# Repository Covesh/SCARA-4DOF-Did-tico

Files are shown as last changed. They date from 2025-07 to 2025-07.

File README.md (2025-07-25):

# Desenvolvimento de um Robô Manipulador SCARA para Fins Didáticos

Este repositório contém os recursos de um projeto focado na conceção, implementação e validação de um robô manipulador SCARA de baixo custo, desenvolvido especificamente para fins didáticos no ensino de robótica. O objetivo é proporcionar uma plataforma prática para o estudo de conceitos fundamentais da mecatrónica e controlo robótico.

  <div align="center">
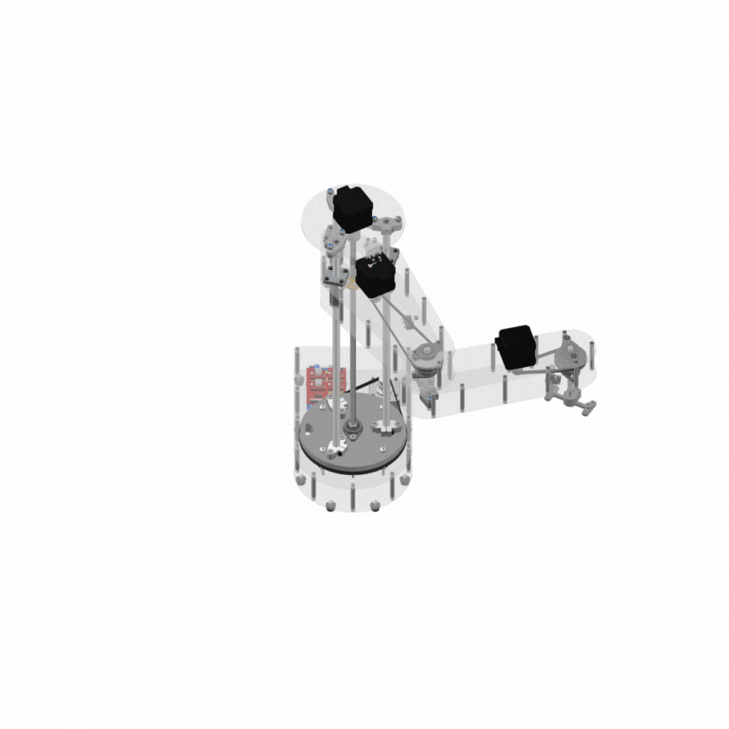
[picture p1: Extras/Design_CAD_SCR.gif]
Design CAD do Robô SCARA
      
      <em>Um GIF que ilustra o design e os movimentos do robô no software CAD.</em>
  </div>

## Descrição do Projeto

O robô é um manipulador do tipo SCARA com 4 graus de liberdade (GDL), onde a sua cinemática inversa foi implementada para uma configuração de 3 GDL (2 rotacionais e 1 prismático), com um 4º GDL rotacional no efetuador final. A sua estrutura é projetada para simplicidade, boa visibilidade dos componentes e fácil acesso, utilizando materiais como acrílico (corte a laser) e PLA (impressão 3D).

<div align="center">
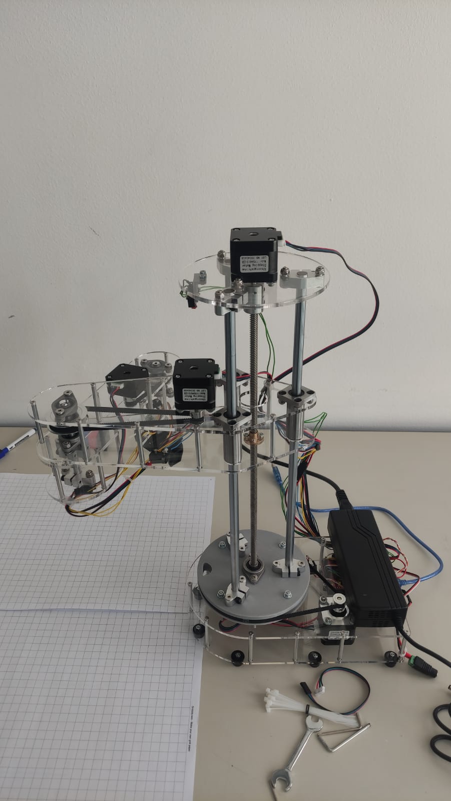
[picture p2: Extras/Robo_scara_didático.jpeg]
Robô SCARA Didático
  
</div>

## Conteúdo do Repositório

* **`💻 /code/arduino`**: Contém o firmware desenvolvido em C/C++ para a placa Arduino Uno, responsável pelo controlo de baixo nível dos motores de passo e do servo motor. Utiliza a biblioteca AccelStepper para perfis de movimento suaves.
* **`🐍 /code/python`**: Contém o software de alto nível (HMI - Interface Gráfica do Utilizador) desenvolvido em Python. Este software realiza cálculos cinemáticos, gere a comunicação serial com o Arduino, e permite a interação do utilizador, incluindo o controlo manual e a gestão de sequências de movimento.
* **`📐 /cad`**: Contém os modelos 3D do manipulador SCARA, desenhados em software CAD (Autodesk Inventor). Inclui ficheiros para corte a laser (.dxf) e impressão 3D (.stl), que podem ser utilizados para replicar a estrutura mecânica.
* **`📄 /docs`**: (A ser adicionado) Documentação detalhada do projeto, incluindo o relatório final, que aborda a fundamentação teórica, o processo de design, a análise cinemática, os testes experimentais e as conclusões.
* **`🎥 /videos`**: Contém vídeos demonstrativos dos testes de funcionamento do robô, incluindo operações de "pick and place" e outros movimentos.

## Principais Funcionalidades e Características ✨

* **Conceção Modular:** Integração de subsistemas mecânicos, eletrónicos e de software.
* **Controlo Abrangente:** Implementação de modelos de cinemática direta e inversa para controlo de movimento preciso.
* **Controlo Eletrónico:** Baseado em Arduino Uno e CNC Shield V3, com drivers A4988 para motores de passo e servo motor para a garra.
* **Interação com Utilizador:** HMI em Python que permite controlo por coordenadas cartesianas/angulares e gestão de sequências.
* **Plataforma Didática:** Recurso de baixo custo e replicável para aprendizagem prática de robótica.

## Demonstrações Visuais ▶️

Aqui pode encontrar exemplos visuais do robô em funcionamento:

* **Vídeos dos Testes:**
    Thumbnail do Vídeo 1 (https://www.youtube.com/watch?v=VIDEO_ID_1)
    _Vídeo 1: Teste de Exatidão e Precisão Posicional._
    Thumbnail do Vídeo 2 (https://www.youtube.com/watch?v=VIDEO_ID_2)
    _Vídeo 2: Demonstração da Tarefa de Pick and Place com Peças de LEGO._

## Como Utilizar 🛠️

Para configurar e operar o robô, siga os passos abaixo:

### Requisitos de Hardware

Certifique-se de que possui os seguintes componentes montados e conectados conforme o diagrama de ligações:

* **Placa Microcontroladora:** Arduino UNO
* **Shield de Expansão:** CNC Shield V3
* **Drivers de Motor de Passo:** 4x A4988
* **Motores de Passo:** 4x NEMA 17 (Modelos HS4023 e 17HS4401S)
* **Servo Motor:** 1x MG996R (para a garra)
* **Sensores de Fim de Curso:** 4x Micro-interruptores de fim de curso
* **Fonte de Alimentação:** 12V (capacidade mínima de 5A, idealmente 9A)
* **Conversor Step-Down:** Para fornecer 5V ao servo motor (se não for alimentado pelo Arduino).
* **Estrutura Mecânica:** Componentes do braço, transmissão (correias e polias), base.

### Requisitos de Software

* **Ambiente de Desenvolvimento Arduino:**
    * Arduino IDE
    * Biblioteca AccelStepper: Pode ser instalada via Gestor de Bibliotecas do Arduino IDE.

* **Ambiente de Desenvolvimento Python:**
    * Python 3.x
    * Bibliotecas Python (podem ser instaladas via `pip`):
        ```bash
        pip install pyserial
        pip install PySide6 # ou PyQt6
        pip install numpy
        pip install pygame
        ```

### Passos de Configuração e Execução

1.  **Montagem do Hardware:** Siga os diagramas de ligação e as instruções de montagem mecânica para construir o robô.
2.  **Upload do Firmware:**
    * Abra o ficheiro `.ino` do firmware localizado em `/code/arduino` na Arduino IDE.
    * Conecte o Arduino ao computador via USB.
    * Selecione a porta e a placa corretas na Arduino IDE.
    * Carregue o firmware para o Arduino.
3.  **Execução do Software HMI:**
    * Navegue até a pasta `/code/python` no seu terminal/linha de comandos.
    * Execute o script principal (geralmente `main.py` ou `hmi.py`):
        ```bash
        python seu_script_principal.py
        ```
4.  **Conexão e Calibração:**
    * A interface gráfica deverá iniciar.
    * Verifique a porta serial correta nas configurações do software Python (se aplicável).
    * Estabeleça a comunicação.
    * Execute a rotina de calibração automática ("Homing") no robô usando a GUI.
5.  **Operação:** Uma vez calibrado, poderá utilizar os controlos da HMI para movimentar o robô, criar e executar sequências, e testar as suas funcionalidades.

## Contribuição 🤝

Este projeto é um esforço académico que visa contribuir para o ensino da robótica.

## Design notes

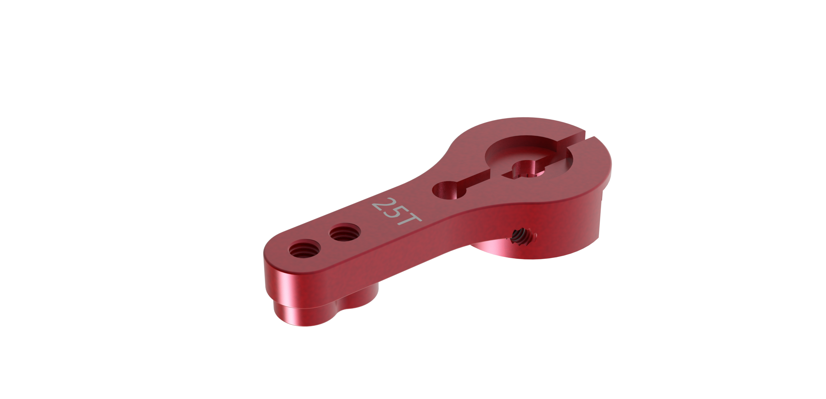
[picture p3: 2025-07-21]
Estrutura Mecânica/SERVO ARM HORN 25T ALUMINIUM/SERVO ARM HORN 25T ALUMINIUM.png

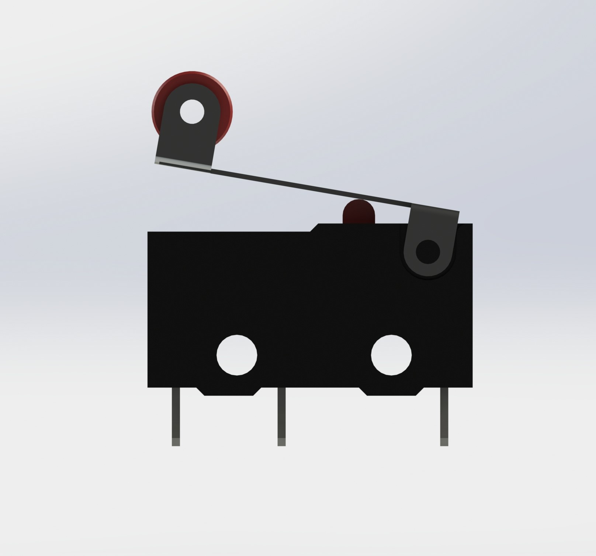
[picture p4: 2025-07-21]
Estrutura Mecânica/Limit switch/render_2.JPG

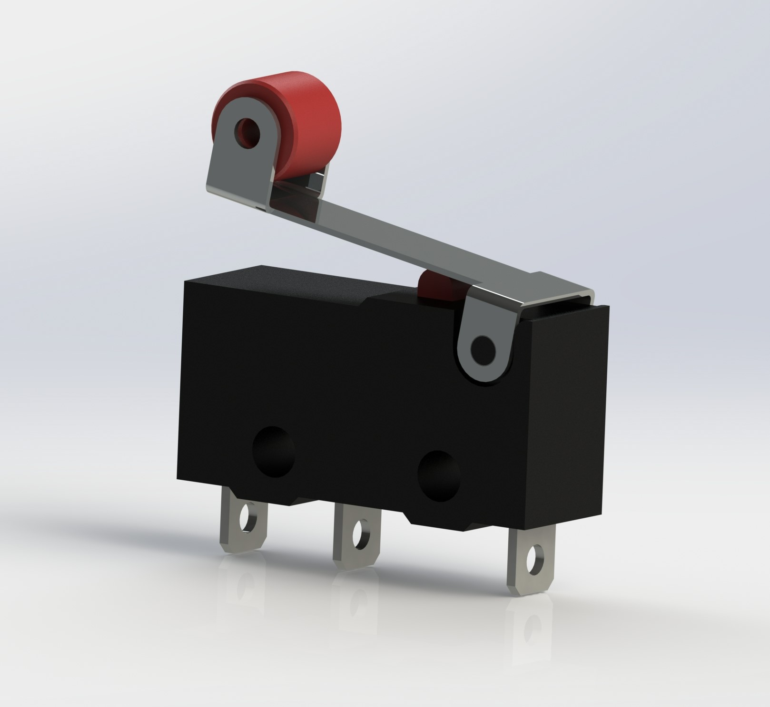
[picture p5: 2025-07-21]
Estrutura Mecânica/Limit switch/render_3.JPG

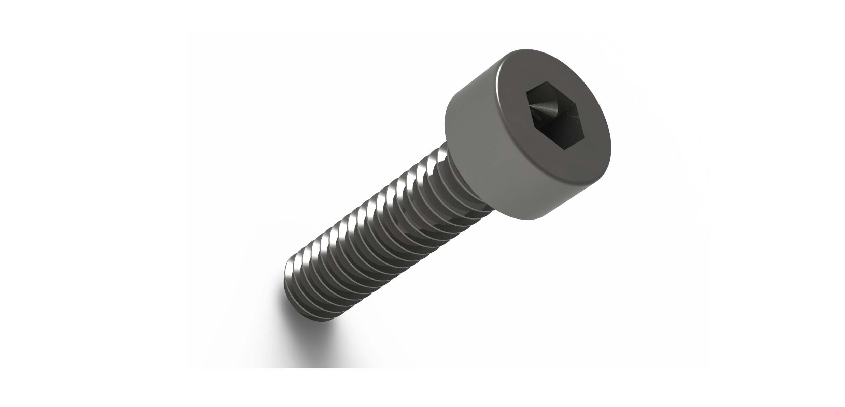
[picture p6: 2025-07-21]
Estrutura Mecânica/SERVO ARM HORN 25T ALUMINIUM/M2 x 8 CAP HEAD HEX SCREW.png

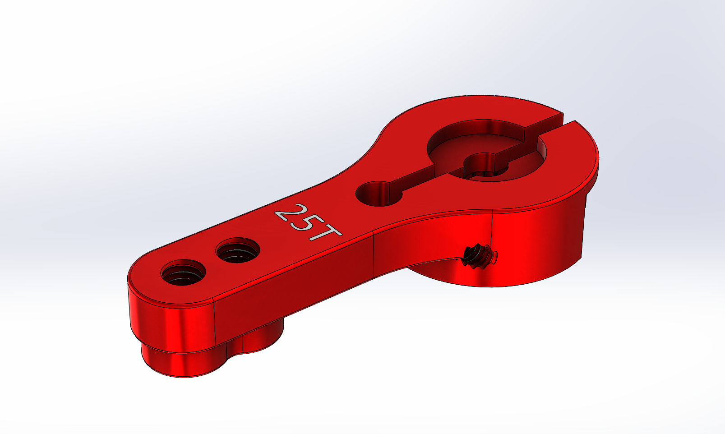
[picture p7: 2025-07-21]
Estrutura Mecânica/SERVO ARM HORN 25T ALUMINIUM/SERVO ARM HORN 25T ALUMINIUM SCREEN GRAB.png

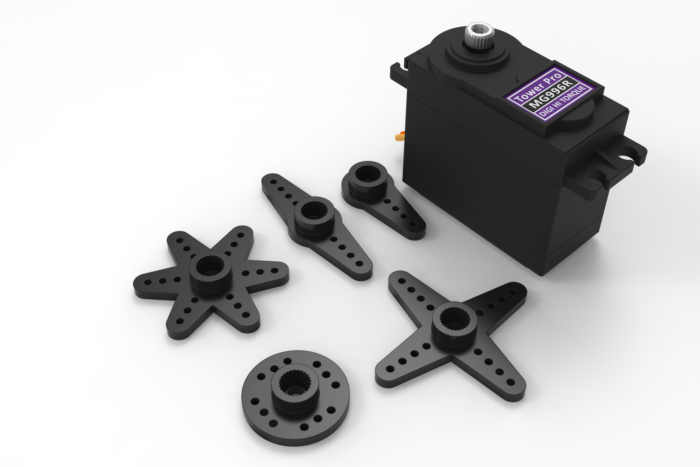
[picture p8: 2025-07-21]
Estrutura Mecânica/MG996R Servo Motor/MG996R Servo Motor.65.png

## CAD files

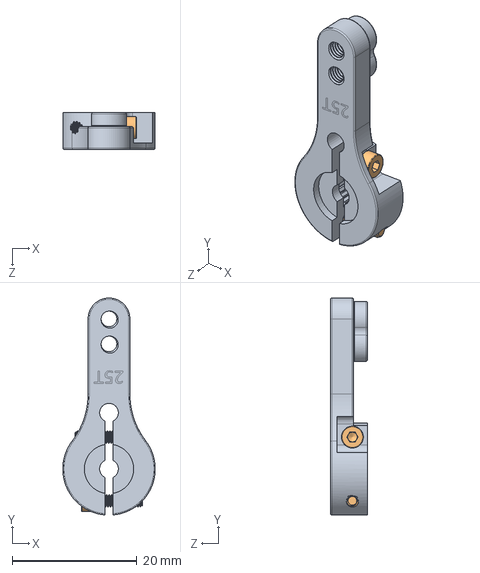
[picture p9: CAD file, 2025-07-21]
Estrutura Mecânica/SERVO ARM HORN 25T ALUMINIUM/SERVO ARM HORN WITH FASTENERS.SLDASM
14.8 x 34.7 x 5.90 mm
SERVO ARM HORN 25T ALUMINIUM
M2 CAP HEAD SOCKET SCREW x 2

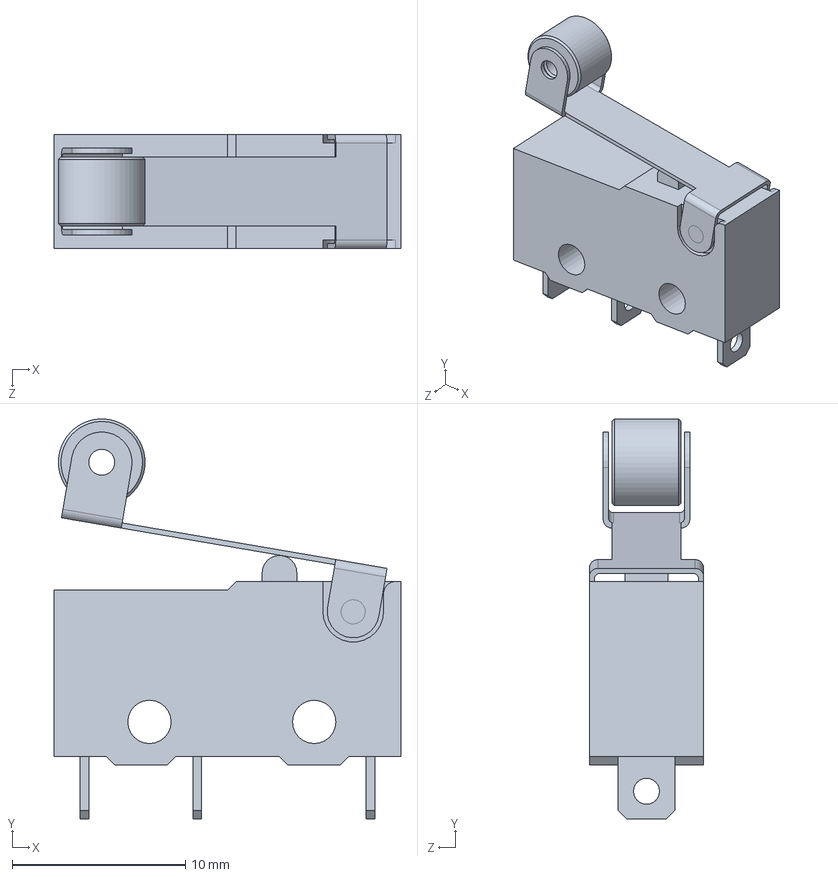
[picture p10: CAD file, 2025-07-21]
Estrutura Mecânica/Limit switch/complete limit switch.SLDPRT
20.0 x 23.1 x 6.60 mm

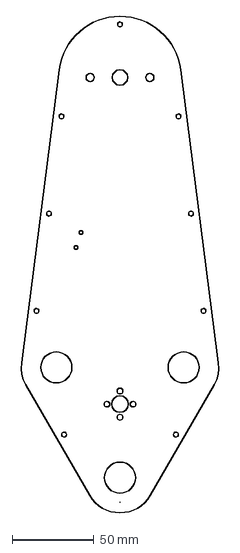
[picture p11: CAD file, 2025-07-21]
Estrutura Mecânica/DXF files/2ELO.dxf
121.8 x 304.0 mm

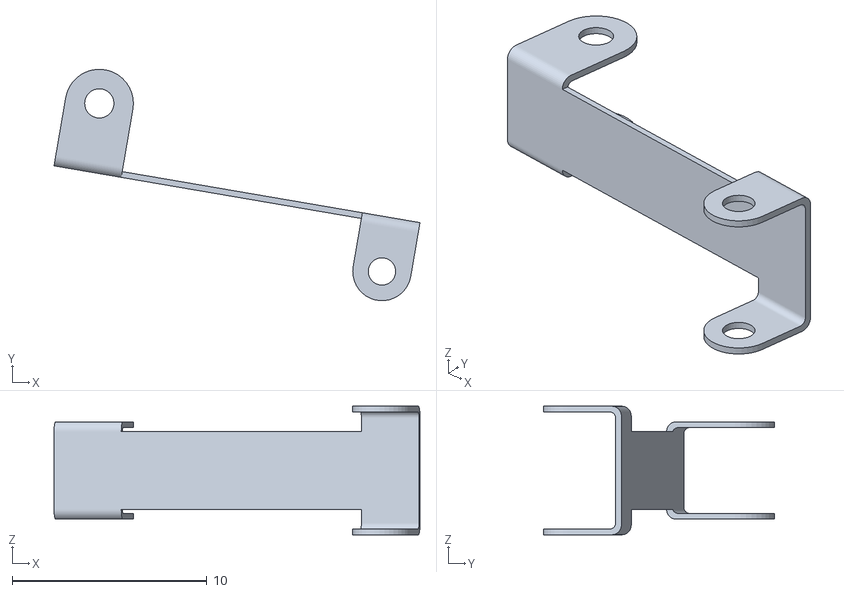
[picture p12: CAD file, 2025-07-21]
Estrutura Mecânica/Limit switch/Assem1 - steel-1.STL
18.8 x 11.9 x 6.60

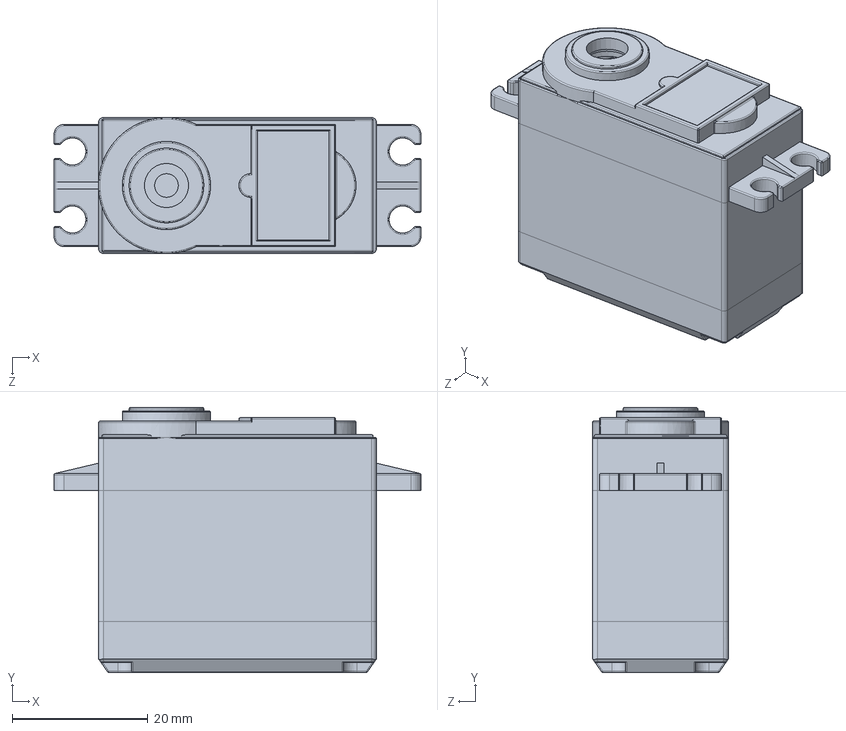
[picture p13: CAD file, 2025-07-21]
Estrutura Mecânica/MG996R Servo Motor/Case.SLDPRT
54.0 x 39.0 x 20.0 mm

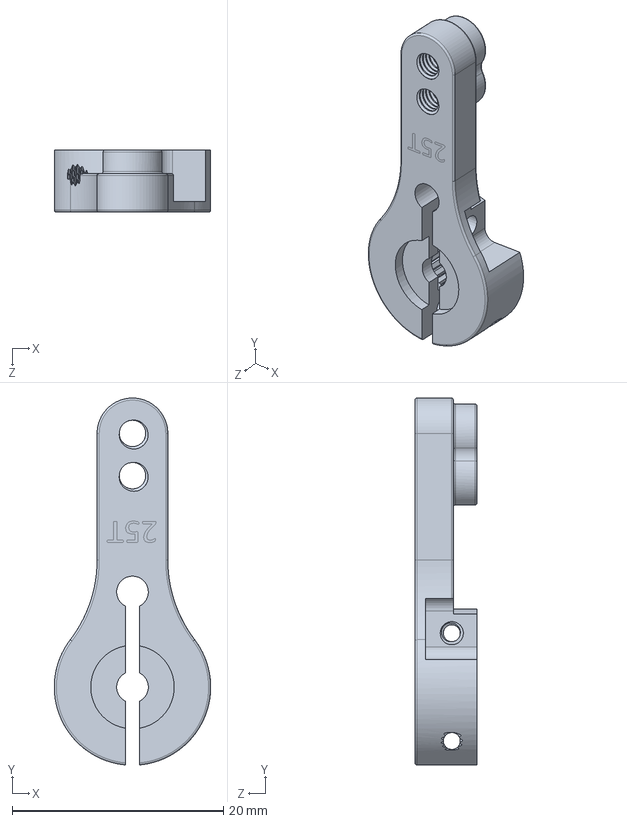
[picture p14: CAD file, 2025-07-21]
Estrutura Mecânica/SERVO ARM HORN 25T ALUMINIUM/SERVO ARM HORN 25T ALUMINIUM.SLDPRT
14.8 x 34.7 x 5.90 mm

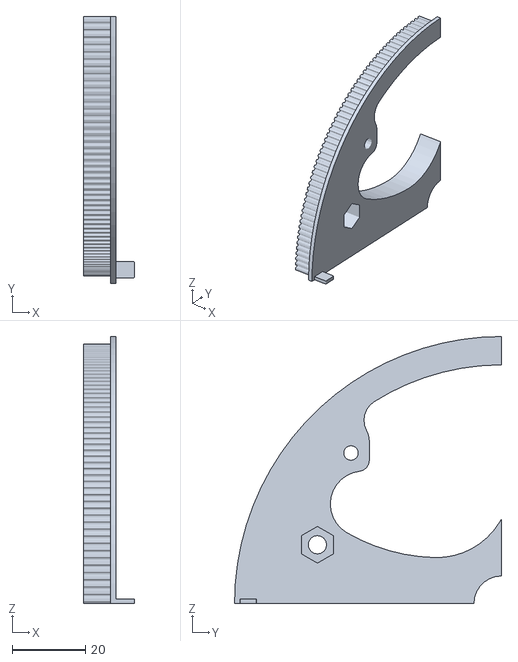
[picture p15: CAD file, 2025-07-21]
Estrutura Mecânica/ttest/GT2Pulley_z220_1-4.STL
13.9 x 72.7 x 72.7

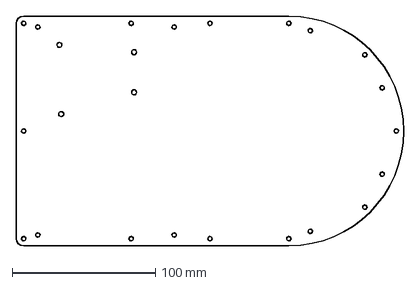
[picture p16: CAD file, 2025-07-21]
Estrutura Mecânica/DXF files/Base_solida_Down.dxf
270.0 x 160.0 mm

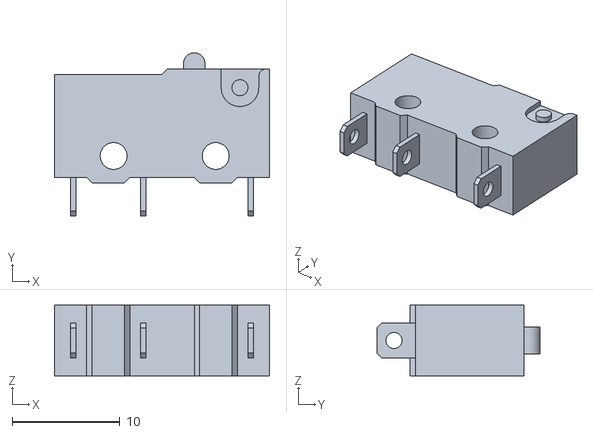
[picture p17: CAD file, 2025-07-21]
Estrutura Mecânica/Limit switch/Assem1 - Limit switch-1.STL
20.0 x 15.2 x 6.60

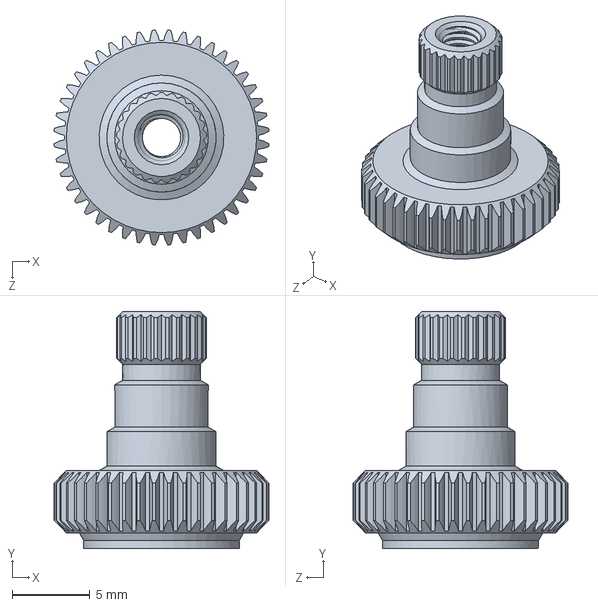
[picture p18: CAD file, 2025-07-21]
Estrutura Mecânica/MG996R Servo Motor/Output Shaft.SLDPRT
13.8 x 15.2 x 13.8 mm

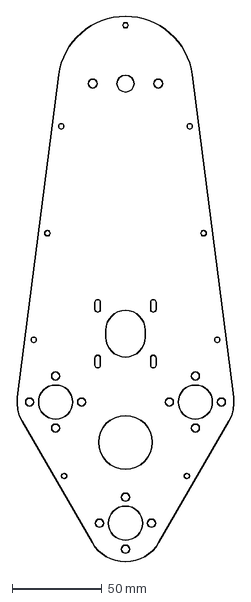
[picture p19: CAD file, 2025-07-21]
Estrutura Mecânica/DXF files/1ELO.dxf
121.8 x 304.0 mm

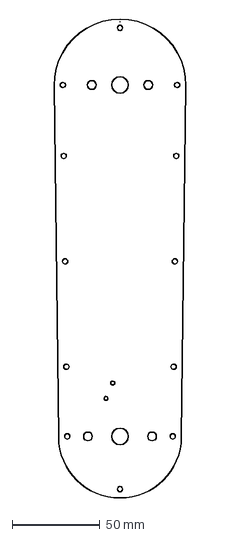
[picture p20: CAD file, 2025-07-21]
Estrutura Mecânica/DXF files/4ELO.dxf
75.3 x 274.2 mm

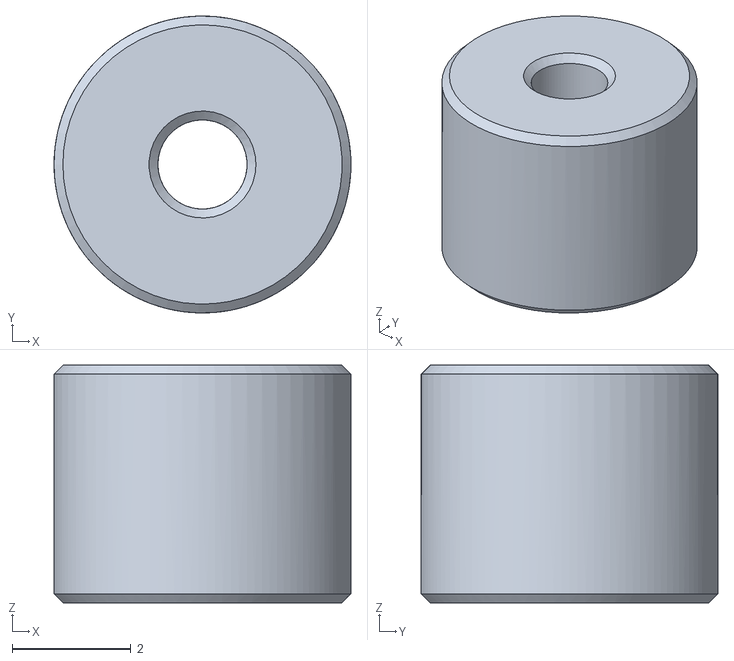
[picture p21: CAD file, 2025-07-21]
Estrutura Mecânica/Limit switch/Assem1 - roller-1.STL
5.00 x 5.00 x 4.00

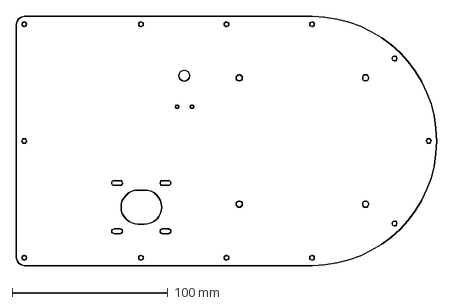
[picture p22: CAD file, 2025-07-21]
Estrutura Mecânica/DXF files/Base_solida.dxf
270.0 x 160.0 mm

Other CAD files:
Estrutura Mecânica/Limit switch/Assem1.STEP
Estrutura Mecânica/Limit switch/roller.STEP
Estrutura Mecânica/MG996R Servo Motor/Rubber Wire Cable Sleeve.SLDPRT
Estrutura Mecânica/DXF files/3ELO.dxf
Estrutura Mecânica/1ELO.ipt
Estrutura Mecânica/2ELO.ipt
Estrutura Mecânica/3ELO.ipt
Estrutura Mecânica/4ELO.ipt
Estrutura Mecânica/AS 1427 H - Metric M3 x0.5 ALTERADO.ipt
Estrutura Mecânica/AS 1427 H - Metric M6 x1 - 10 Alterado.ipt
Estrutura Mecânica/Amortecedor_Borracha.ipt
Estrutura Mecânica/Anilha_M3.ipt
Estrutura Mecânica/Anilha_M4.ipt
Estrutura Mecânica/Arduino_CNC_Assembly.iam
Estrutura Mecânica/Arduino_CNC_Assembly/Arduino_CNC_Assembly/0603 Package (10).stp.ipt
Estrutura Mecânica/Arduino_CNC_Assembly/Arduino_CNC_Assembly/0603 Package (11).stp.ipt
Estrutura Mecânica/Arduino_CNC_Assembly/Arduino_CNC_Assembly/0603 Package (12).stp.ipt
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

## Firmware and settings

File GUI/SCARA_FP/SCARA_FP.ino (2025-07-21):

// =================================================================
//
//   Editar
//
// =================================================================

#include <AccelStepper.h>
#include <Servo.h> 
#include <math.h>

// ======== Definições de Pinos e Constantes Físicas ========
#define EN_PIN 8
#define LIMIT_J1_PIN 9
#define LIMIT_J2_PIN 11
#define LIMIT_J3_PIN 10
#define LIMIT_J4_PIN 17

// --- Definições para o Servo da Garra ---
#define SERVO_PIN A0
const int SERVO_OPEN_ANGLE = 45;
const int SERVO_CLOSE_ANGLE = 175;


// --- Constantes Físicas do Robô (Calibradas) ---
// a1: Altura total desde a base até à junta do efetuador quando d2=0.
// a3: Comprimento vertical do link do efetuador.
// a5: Altura da garra.
// L1, L2: Comprimento dos braços principais do SCARA.
const double a1 = 370.7, a2 = 200.0, a3 = 53.7, a4 = 200.0;
const double a5 = 147.0;
const double L1 = 200.0, L2 = 200.0;

// --- Constantes dos Motores de Passo ---
const double STEPS_PER_REV_BASE = 200.0;
const int     GEAR_RATIO_J1 = 11, GEAR_RATIO_J3 = 3, GEAR_RATIO_J4 = 3;
const int     MICROSTEP_J1 = 16, MICROSTEP_J2 = 8, MICROSTEP_J3 = 16, MICROSTEP_J4 = 8;
const double LEAD_SCREW_PITCH_J2 = 8.0; // Passo de 8mm do fuso da junta 2
const double STEPS_PER_MM_J2 = (STEPS_PER_REV_BASE * MICROSTEP_J2) / LEAD_SCREW_PITCH_J2;

// ======== Constantes de Homing ========
const float  HOMING_SPEED_FAST = 1000.0, HOMING_SPEED_SLOW = 100.0;
const float  HOMING_SPEED_SLOW_J3 = 250.0;
const float  HOMING_ACCELERATION = 1000.0;
const double HOMING_BACKOFF_DEG  = 5.0, HOMING_BACKOFF_MM = 5.0;
const int    LIMIT_SWITCH_ACTIVE_STATE = LOW;

// ======== Posições e Offsets de Home ========
const double J1_HOME_POS_DEG = 0.0, J2_HOME_POS_MM  = 0.0, J3_HOME_POS_DEG = 0.0, J4_HOME_POS_DEG = 0.0;
const double J1_HOME_OFFSET_DEG = 5.0, J2_HOME_OFFSET_MM  = 2.0, J3_HOME_OFFSET_DEG = 136.0, J4_HOME_OFFSET_DEG = 143.0;

// ======== Limites de Software ========
const double J1_MIN_DEG = 0.0,   J1_MAX_DEG = 180.0;
const double J2_MIN_MM  = 0.0,   J2_MAX_MM  = 170.0; 
const double J3_MIN_DEG = -135.0, J3_MAX_DEG = 135.0;
const double J4_MIN_DEG = -135.0, J4_MAX_DEG = 135.0;

// ======== Constantes para HMI Avançada ========
const float SPEED_J1 = 6000, SPEED_J2 = 4000, SPEED_J3 = 4000, SPEED_J4 = 1500;
const float ACCEL_J1 = 2500, ACCEL_J2 = 2000, ACCEL_J3 = 2000, ACCEL_J4 = 1000;

// ======== Instâncias e Variáveis Globais ========
AccelStepper stp1(1, 2, 5); AccelStepper stp2(1, 3, 6);
AccelStepper stp3(1, 4, 7); AccelStepper stp4(1, 12, 13);
Servo gripperServo; 

bool is_moving = false, is_calibrated = false, is_calibrating = false, motors_enabled = false;
String inputString = "";
float speed_multiplier = 1.0;
double current_j1=0, current_d2=0, current_j3=0, current_j4=0, current_x=0, current_y=0, current_z=0;
int current_servo_angle = SERVO_OPEN_ANGLE; 

// Variáveis para o temporizador não-bloqueante da garra
bool is_gripper_timer_active = false;
unsigned long gripper_timer_start = 0;
const unsigned long GRIPPER_MOVE_TIME = 600; // Tempo em ms para a garra se mover

// ======== Funções Principais ========
void setup() {
  Serial.begin(9600); inputString.reserve(200);
  pinMode(EN_PIN, OUTPUT); digitalWrite(EN_PIN, HIGH);
  pinMode(LIMIT_J1_PIN, INPUT_PULLUP); pinMode(LIMIT_J2_PIN, INPUT_PULLUP);
  pinMode(LIMIT_J3_PIN, INPUT_PULLUP); pinMode(LIMIT_J4_PIN, INPUT_PULLUP);
  
  //stp1.setEnablePin(EN_PIN);
  stp1.setPinsInverted(false, false, true);
  //stp2.setEnablePin(EN_PIN); 
  stp2.setPinsInverted(false, false, true);
  //stp3.setEnablePin(EN_PIN); 
  stp3.setPinsInverted(true, false, true);
  //stp4.setEnablePin(EN_PIN); 
  stp4.setPinsInverted(true, false, true);
  updateMotorSpeeds(); Serial.println("MSG:Robo SCARA pronto.");
}

void loop() {
  // Verifica se há novos comandos na porta serial
  if (Serial.available() > 0) {
    char receivedChar = Serial.read();
    if (receivedChar == '\n') { 
      handleCommand(inputString); 
      inputString = ""; 
    } else { 
      inputString += receivedChar; 
    }
  }
  
  // Se os motores estiverem em movimento, executa o passo seguinte
  if (is_moving) {
    bool m1 = stp1.run(), m2 = stp2.run(), m3 = stp3.run(), m4 = stp4.run();
    // Se todos os motores pararam, o movimento terminou
    if (!m1 && !m2 && !m3 && !m4) {
      is_moving = false; 
      updateCurrentPosition(); 
      reportPosition(); 
      Serial.println("MSG:Movimento concluido.");
    }
  }

  // Gestor do temporizador não-bloqueante da garra
  if (is_gripper_timer_active) {
    // Verifica se já passou o tempo definido para o movimento da garra
    if (millis() - gripper_timer_start >= GRIPPER_MOVE_TIME) {
      is_gripper_timer_active = false; // Desativa o temporizador
      // Se a posição final for a de "aberto", desliga o servo para economizar energia
      if (current_servo_angle == SERVO_OPEN_ANGLE) {
        gripperServo.detach();
      }
    }
  }
}

/**
 * @brief Interpreta e executa os comandos recebidos via serial.
 * @param command A string de comando recebida da HMI.
 */
void handleCommand(String command) {
  command.trim();
  if (!command.startsWith("GOTO_IK")) { Serial.print("Comando Recebido: "); Serial.println(command); }
  
  if (command == "E_STOP") {
    stp1.stop(); stp2.stop(); stp3.stop(); stp4.stop();
    is_moving = false;
    digitalWrite(EN_PIN, HIGH); motors_enabled = false;
    Serial.println("MSG:PARAGEM DE EMERGENCIA.");
    Serial.println("MSG:Motores DESLIGADOS");
  } else if (command == "AUTO_CAL") {
    if (is_calibrating) { Serial.println("MSG:Calibracao ja em andamento."); }
    else { runAutoCalibration(); }
  } else if (command.startsWith("GOTO_IK:")) {
    if (!is_calibrated || !motors_enabled) { Serial.println("ERR:NOT_READY"); return; }
    command.remove(0, 8); char cmdBuffer[50]; command.toCharArray(cmdBuffer, 50);
    float x=atof(strtok(cmdBuffer,",")); float y=atof(strtok(NULL,","));
    float z=atof(strtok(NULL,",")); float u=atof(strtok(NULL,","));
    moveToPosition(x, y, z, u);
  } else if (command.startsWith("GOTO_JOINTS:")) {
    if (!is_calibrated || !motors_enabled) { Serial.println("ERR:NOT_READY"); return; }
    command.remove(0, 12); char cmdBuffer[50]; command.toCharArray(cmdBuffer, 50);
    float t1=atof(strtok(cmdBuffer,",")); float d2=atof(strtok(NULL,","));
    float t3=atof(strtok(NULL,",")); float t4=atof(strtok(NULL,","));
    moveToJoints(t1, d2, t3, t4);
  } else if (command.startsWith("GOTO_HOME")) {
    if (!is_calibrated || !motors_enabled) { Serial.println("ERR:NOT_READY"); return; }
    moveToJoints(J1_HOME_POS_DEG, J2_HOME_POS_MM, J3_HOME_POS_DEG, J4_HOME_POS_DEG);
  } else if (command.startsWith("SET_SPEED_MULT:")) {
    command.remove(0, 15); speed_multiplier = command.toFloat();
    if (speed_multiplier < 0.5) speed_multiplier = 0.5; if (speed_multiplier > 1.5) speed_multiplier = 1.5;
    updateMotorSpeeds(); Serial.print("MSG:Speed multiplier set to "); Serial.println(speed_multiplier);
  } else if (command.startsWith("MOTORS:")) {
      command.remove(0, 7); int state = command.toInt();
      if(state == 1 && is_calibrated) {
          digitalWrite(EN_PIN, LOW); motors_enabled = true; Serial.println("MSG:Motores LIGADOS");
      } else {
          digitalWrite(EN_PIN, HIGH); motors_enabled = false; Serial.println("MSG:Motores DESLIGADOS");
      }
  } else if (command == "GRIPPER_OPEN") {
      setGripperAngle(SERVO_OPEN_ANGLE);
      Serial.println("MSG:Garra aberta.");
      reportPosition();
  } else if (command == "GRIPPER_CLOSE") {
      setGripperAngle(SERVO_CLOSE_ANGLE);
      Serial.println("MSG:Garra fechada.");
      reportPosition();
  } else if (command.startsWith("GRIPPER_SET:")) {
      command.remove(0, 12);
      int angle = command.toInt();
      setGripperAngle(angle);
      reportPosition();
  } else { Serial.println("ERR:UNKNOWN_COMMAND"); }
}

/**
 * @brief Move o servo da garra e ativa um temporizador para o desligar.
 * Esta função não usa delay(), permitindo que os outros motores continuem a funcionar.
 * @param angle O ângulo alvo para o servo.
 */
void setGripperAngle(int angle) {
  angle = constrain(angle, SERVO_OPEN_ANGLE, SERVO_CLOSE_ANGLE);

  if (!gripperServo.attached()) {
    gripperServo.attach(SERVO_PIN);
    delay(15); 
  }

  gripperServo.write(angle);
  current_servo_angle = angle; 

  is_gripper_timer_active = true;
  gripper_timer_start = millis();
}

// Atualiza a velocidade e aceleração de todos os motores.

void updateMotorSpeeds() {
  stp1.setMaxSpeed(SPEED_J1 * speed_multiplier); stp1.setAcceleration(ACCEL_J1 * speed_multiplier);
  stp2.setMaxSpeed(SPEED_J2 * speed_multiplier); stp2.setAcceleration(ACCEL_J2 * speed_multiplier);
  stp3.setMaxSpeed(SPEED_J3 * speed_multiplier); stp3.setAcceleration(ACCEL_J3 * speed_multiplier);
  stp4.setMaxSpeed(SPEED_J4 * speed_multiplier); stp4.setAcceleration(ACCEL_J4 * speed_multiplier);
}

/**
 * @brief Lê a posição atual dos motores (em passos) e converte para unidades de engenharia (graus/mm).
 */
void updateCurrentPosition() {
  current_j1 = (double)stp1.currentPosition() * 360.0 / (STEPS_PER_REV_BASE * MICROSTEP_J1 * GEAR_RATIO_J1);
  current_d2 = (double)stp2.currentPosition() / STEPS_PER_MM_J2;
  current_j3 = (double)stp3.currentPosition() * 360.0 / (STEPS_PER_REV_BASE * MICROSTEP_J3 * GEAR_RATIO_J3);
  current_j4 = (double)stp4.currentPosition() * 360.0 / (STEPS_PER_REV_BASE * MICROSTEP_J4 * GEAR_RATIO_J4);
  calculateForwardKinematics(current_j1, current_d2, current_j3, current_x, current_y, current_z);
}

//Executa a rotina de calibração automática para todas as juntas.
 
void runAutoCalibration() {
  is_calibrating = true; motors_enabled = true; digitalWrite(EN_PIN, LOW); delay(100);
  Serial.println("MSG:Iniciando auto-calibracao...");
  Serial.println("MSG:Homing J2...");
  performHomingForPrismaticJoint(stp2, LIMIT_J2_PIN, STEPS_PER_MM_J2, J2_HOME_OFFSET_MM, J2_HOME_POS_MM, -1);
  Serial.println("MSG:Homing J1...");
  performHomingForJoint(stp1, LIMIT_J1_PIN, GEAR_RATIO_J1, MICROSTEP_J1, J1_HOME_OFFSET_DEG, J1_HOME_POS_DEG, -1, HOMING_SPEED_SLOW);
  Serial.println("MSG:Homing J3...");
  performHomingForJoint(stp3, LIMIT_J3_PIN, GEAR_RATIO_J3, MICROSTEP_J3, J3_HOME_OFFSET_DEG, J3_HOME_POS_DEG, -1, HOMING_SPEED_SLOW_J3);
  Serial.println("MSG:Homing J4...");
  performHomingForJoint(stp4, LIMIT_J4_PIN, GEAR_RATIO_J4, MICROSTEP_J4, J4_HOME_OFFSET_DEG, J4_HOME_POS_DEG, -1, HOMING_SPEED_SLOW);
  
  is_calibrated = true; 
  updateCurrentPosition(); 
  reportPosition();


  Serial.println("MSG:Testando garra...");
  for (int i = 0; i < 2; i++) {
    setGripperAngle(SERVO_CLOSE_ANGLE);
    delay(700); 
    setGripperAngle(SERVO_OPEN_ANGLE);
    delay(700); 
  }

  Serial.println("MSG:Calibracao concluida."); 
  is_calibrating = false;
  Serial.println("MSG:Motores LIGADOS");
}

void performHomingForJoint(AccelStepper &stepper, int limitSwitchPin, int gearRatio, int microstepFactor, double homeOffsetDeg, double finalHomeDeg, int homingDirection, float slow_speed) {
  stepper.setMaxSpeed(HOMING_SPEED_FAST); stepper.setAcceleration(HOMING_ACCELERATION);
  stepper.move(homingDirection * 1000000);
  while (digitalRead(limitSwitchPin) != LIMIT_SWITCH_ACTIVE_STATE) { stepper.run(); }
  stepper.stop(); delay(50); stepper.setCurrentPosition(0);
  long backoff_steps = (long)((-homingDirection) * HOMING_BACKOFF_DEG / 360.0 * (STEPS_PER_REV_BASE * microstepFactor * gearRatio));
  stepper.moveTo(backoff_steps);
  while (stepper.distanceToGo() != 0) { stepper.run(); }
  delay(50);
  stepper.move(homingDirection * 2 * 1000000); stepper.setMaxSpeed(slow_speed);
  while (digitalRead(limitSwitchPin) != LIMIT_SWITCH_ACTIVE_STATE) { stepper.run(); }
  stepper.stop(); delay(50); stepper.setCurrentPosition(0);
  long offset_steps = (long)((homeOffsetDeg / 360.0) * (STEPS_PER_REV_BASE * microstepFactor * gearRatio));
  stepper.moveTo(offset_steps); stepper.setMaxSpeed(HOMING_SPEED_FAST);
  while (stepper.distanceToGo() != 0) { stepper.run(); }
  long final_home_steps = (long)((finalHomeDeg / 360.0) * (STEPS_PER_REV_BASE * microstepFactor * gearRatio));
  stepper.setCurrentPosition(final_home_steps);
  Serial.println("  Homing da junta concluido.");
}

void performHomingForJoint(AccelStepper &stepper, int limitSwitchPin, int gearRatio, int microstepFactor, double homeOffsetDeg, double finalHomeDeg, int homingDirection) {
  performHomingForJoint(stepper, limitSwitchPin, gearRatio, microstepFactor, homeOffsetDeg, finalHomeDeg, homingDirection, HOMING_SPEED_SLOW);
}

void performHomingForPrismaticJoint(AccelStepper &stepper, int limitSwitchPin, double stepsPerMm, double homeOffsetMm, double finalHomeMm, int homingDirection) {
  stepper.setMaxSpeed(HOMING_SPEED_FAST); stepper.setAcceleration(HOMING_ACCELERATION);
  stepper.move(homingDirection * 1000000);
  while (digitalRead(limitSwitchPin) != LIMIT_SWITCH_ACTIVE_STATE) { stepper.run(); }
  stepper.stop(); delay(50); stepper.setCurrentPosition(0);
  long backoff_steps = (long)((-homingDirection) * HOMING_BACKOFF_MM * stepsPerMm);
  stepper.moveTo(backoff_steps);
  while (stepper.distanceToGo() != 0) { stepper.run(); }
  delay(50);
  stepper.move(homingDirection * 2 * 1000000); stepper.setMaxSpeed(HOMING_SPEED_SLOW);
  while (digitalRead(limitSwitchPin) != LIMIT_SWITCH_ACTIVE_STATE) { stepper.run(); }
  stepper.stop(); delay(50); stepper.setCurrentPosition(0);
  long offset_steps = (long)(homeOffsetMm * stepsPerMm);
  stepper.moveTo(offset_steps); stepper.setMaxSpeed(HOMING_SPEED_FAST);
  while (stepper.distanceToGo() != 0) { stepper.run(); }
  long final_home_steps = (long)(finalHomeMm * stepsPerMm);
  stepper.setCurrentPosition(final_home_steps);
  Serial.println("  Homing da junta concluido.");
}


// Calcula a cinemática inversa: converte coordenadas (X,Y,Z) em ângulos das juntas (t1,d2,t3).
// true se a solução for válida e dentro dos limites, false caso contrário.

bool calculateInverseKinematics(double x, double y, double z, double target_teta4_deg, bool elbow_up_preference, double *t1_ptr, double *d2_ptr, double *t3_ptr, double *t4_ptr) {
    double d2_calc = a1 - a3 - a5 - z;
    double r_sq = x*x + y*y;

    if (r_sq > (L1 + L2) * (L1 + L2)) return false;

    double cos_t3 = (r_sq - L1*L1 - L2*L2) / (2 * L1 * L2);

    if (cos_t3 > 1.0) cos_t3 = 1.0;
    if (cos_t3 < -1.0) cos_t3 = -1.0;

    for (int i = 0; i < 2; ++i) {
        bool use_elbow_up = (i == 0) ? elbow_up_preference : !elbow_up_preference;
        
        double t3_rad = acos(cos_t3);
        if (use_elbow_up) {
            t3_rad = -t3_rad;
        }

        double k1 = L1 + L2 * cos(t3_rad);
        double k2 = L2 * sin(t3_rad);
        double t1_rad = atan2(y, x) - atan2(k2, k1);

        double t1_deg = degrees(t1_rad);
        double t3_deg = degrees(t3_rad);

        if (t1_deg >= J1_MIN_DEG && t1_deg <= J1_MAX_DEG &&
            d2_calc >= J2_MIN_MM  && d2_calc <= J2_MAX_MM &&
            t3_deg >= J3_MIN_DEG && t3_deg <= J3_MAX_DEG) {
            
            *t1_ptr = t1_deg;
            *d2_ptr = d2_calc;
            *t3_ptr = t3_deg;
            *t4_ptr = target_teta4_deg;
            return true;
        }
    }
    return false;
}

// Move o robô para uma posição cartesiana (X,Y,Z,U).

void moveToPosition(double x, double y, double z, double u) {
    double t1, d2, t3, t4;
    bool success = calculateInverseKinematics(x, y, z, u, false, &t1, &d2, &t3, &t4); 
    
    if (success) {
        if (t4 < J4_MIN_DEG || t4 > J4_MAX_DEG) { Serial.println("ERR:LIMIT_J4"); return; }
        moveToJoints(t1, d2, t3, t4);
    } else {
        Serial.println("ERR:UNREACHABLE_OR_LIMITS");
    }
}


// juntas individuais para os seus ângulos/posições alvo.

void moveToJoints(double t1, double d2, double t3, double t4) {
  is_moving = true;
  long steps1 = (t1 / 360.0) * (STEPS_PER_REV_BASE * MICROSTEP_J1 * GEAR_RATIO_J1);
  long steps2 = d2 * STEPS_PER_MM_J2;
  long steps3 = (t3 / 360.0) * (STEPS_PER_REV_BASE * MICROSTEP_J3 * GEAR_RATIO_J3);
  long steps4 = (t4 / 360.0) * (STEPS_PER_REV_BASE * MICROSTEP_J4 * GEAR_RATIO_J4);
  stp1.moveTo(steps1); stp2.moveTo(steps2); stp3.moveTo(steps3); stp4.moveTo(steps4);
}


// @brief Calcula a cinemática direta: converte ângulos das juntas (j1,d2,j3) em coordenadas (X,Y,Z).

void calculateForwardKinematics(double j1, double d2, double j3, double& x, double& y, double& z) {
  double t1_rad = radians(j1); double t3_rad = radians(j3);
  x = L1 * cos(t1_rad) + L2 * cos(t1_rad + t3_rad);
  y = L1 * sin(t1_rad) + L2 * sin(t1_rad + t3_rad);
  z = a1 - d2 - a3 - a5;
}


// @brief Envia a posição atual do robô (juntas e cartesiana) pela porta serial.
void reportPosition() {
  Serial.print("POS:"); Serial.print(current_j1, 2); Serial.print(","); Serial.print(current_d2, 2); Serial.print(",");
  Serial.print(current_j3, 2); Serial.print(","); Serial.println(current_j4, 2);
  Serial.print("WPOS:"); Serial.print(current_x, 2); Serial.print(","); Serial.print(current_y, 2); Serial.print(",");
  Serial.print(current_z, 2); Serial.print(","); Serial.println(current_j4, 2);
  Serial.print("GRIPPER:"); Serial.println(current_servo_angle);
}

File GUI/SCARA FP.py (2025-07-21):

import sys
import serial
import time
import json
from pathlib import Path
from PySide6.QtWidgets import (QApplication, QMainWindow, QWidget, QVBoxLayout, QHBoxLayout,
                                 QPushButton, QLabel, QGridLayout, QFrame, QLineEdit, QTabWidget,
                                 QSlider, QStatusBar, QScrollArea, QCheckBox, QFileDialog)
from PySide6.QtCore import QThread, QObject, Signal, Slot, Qt, QTimer, QFile
from PySide6.QtGui import QIcon

# --- CONFIGURAÇÕES ---
ARDUINO_PORT = "COM14"  # VerifiCA a porta serial do Arduino
BAUDRATE = 9600
SEQUENCE_FILE = Path("sequences.json")  # Ficheiro para guardar automaticamente as sequências
MAX_SEQUENCE_POSITIONS = 10
JOG_INTERVAL_MS = 150
JOG_STEP_XY = 2.0
JOG_STEP_Z = 1.0
JOG_STEP_U = 2.0

# --- Worker para Comunicação Serial ---
# Esta classe corre numa thread separada para não bloquear a interface gráfica enquanto espera por dados da porta serial.
class SerialWorker(QObject):
    data_received = Signal(str)
    connection_failed = Signal(str)

    def __init__(self, port, baudrate):
        super().__init__()
        self.port, self.baudrate = port, baudrate
        self.is_running = True
        self.ser = None

    @Slot()
    def run(self):
        try:
            self.ser = serial.Serial(self.port, self.baudrate, timeout=1)
            time.sleep(2) # Espera para a conexão serial estabilizar
            self.data_received.emit("MSG:Conexão estabelecida.")
            while self.is_running:
                if self.ser and self.ser.in_waiting > 0:
                    try:
                        line = self.ser.readline().decode('utf-8').strip()
                        if line: 
                            self.data_received.emit(line)
                    except UnicodeDecodeError: 
                        # Ignora erros de decodificação que podem acontecer
                        pass
                time.sleep(0.05)
            if self.ser: self.ser.close()
        except serial.SerialException as e:
            self.connection_failed.emit(str(e))

    def stop(self):
        self.is_running = False

# --- Classe Principal da Interface Gráfica (HMI) ---
class HMI_Completa(QMainWindow):
    # Constantes para mapeamento da garra de ângulo para milímetros
    GRIPPER_ANGLE_OPEN = 45
    GRIPPER_ANGLE_CLOSE = 175
    GRIPPER_MM_OPEN = 32.0
    GRIPPER_MM_CLOSE = 1.5

    def __init__(self):
        super().__init__()
        self.setWindowTitle("HMI SCARA - TA")
        self.setGeometry(100, 100, 950, 850)

        # Variáveis de estado para controlar o robô e a interface
        self.motors_on = False
        self.is_running_sequence = False
        self.graceful_stop_requested = False
        self.robot_current_wpos = [0.0] * 4
        self.robot_current_jpos = [0.0] * 4
        self.robot_current_gripper_angle = self.GRIPPER_ANGLE_OPEN
        self.sequence_to_run = []
        self.current_sequence_step = 0
        self.running_seq_num = -1
        
        self.load_sequences() # Carrega as sequências do ficheiro JSON
        self.setup_ui()       # Constrói todos os widgets da interface
        self.setup_connections() # Liga os botões às suas funções
        self.setup_serial()      # Inicia a comunicação com o Arduino
        self.update_gripper_ui(self.robot_current_gripper_angle) # Garante que a UI da garra está correta no arranque

    def setup_ui(self):
        """Cria a estrutura principal da interface gráfica."""
        main_container = QWidget()
        self.setCentralWidget(main_container)
        container_layout = QVBoxLayout(main_container)
        container_layout.setContentsMargins(0,0,0,0)
        scroll_area = QScrollArea()
        scroll_area.setWidgetResizable(True)
        container_layout.addWidget(scroll_area)
        content_widget = QWidget()
        scroll_area.setWidget(content_widget)
        self.main_layout = QVBoxLayout(content_widget)
        self.main_layout.setSpacing(10)
        
        # Criação dos diferentes painéis da UI
        self.create_top_control_panel()
        self.create_tabs()
        self.create_gripper_panel() 
        self.create_position_panel()
        self.create_sequence_panel()
        self.main_layout.addStretch()
        self.create_status_bar()

    def create_top_control_panel(self):
        """Cria os botões de controlo principais (Calibrar, Home, Stop, etc.)."""
        top_frame = QFrame()
        top_layout = QHBoxLayout(top_frame)
        
        self.btn_autocal = QPushButton("Calibrar")
        self.btn_autocal.setStyleSheet("background-color: #D08770; color: white;")

        self.btn_gohome = QPushButton("Home")
        self.btn_gohome.setStyleSheet("background-color: #A3BE8C;")

        self.btn_toggle_motors = QPushButton("⏻")
        self.btn_toggle_motors.setToolTip("Motores Desligados")
        
        self.btn_estop = QPushButton("STOP")
        self.btn_estop.setToolTip("PARAGEM DE EMERGÊNCIA")
        self.btn_estop.setStyleSheet("background-color: #BF616A; color: white; font-weight: bold;")
        
        top_layout.addWidget(self.btn_autocal)
        top_layout.addWidget(self.btn_gohome)
        top_layout.addStretch()
        top_layout.addWidget(self.btn_toggle_motors)
        top_layout.addWidget(self.btn_estop)
        
        self.main_layout.addWidget(top_frame)

    def create_tabs(self):
        """Cria as abas para controlo por IK (Jogging) e FK (Juntas)."""
        self.tabs = QTabWidget()
        self.main_layout.addWidget(self.tabs)
        ik_tab = QWidget()
        self.populate_ik_tab(QVBoxLayout(ik_tab))
        self.tabs.addTab(ik_tab, "Controlo IK (Jogging)")
        fk_tab = QWidget()
        self.populate_fk_tab(QVBoxLayout(fk_tab))
        self.tabs.addTab(fk_tab, "Controlo FK (Juntas Individuais)")
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
